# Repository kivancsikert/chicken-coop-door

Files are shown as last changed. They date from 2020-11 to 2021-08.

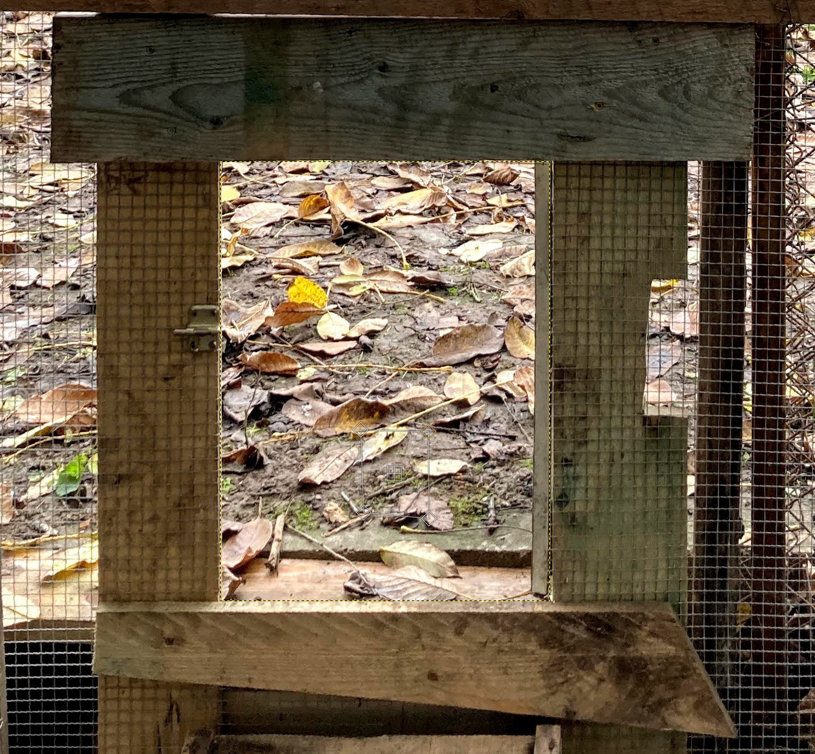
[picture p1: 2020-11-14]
frame.jpg

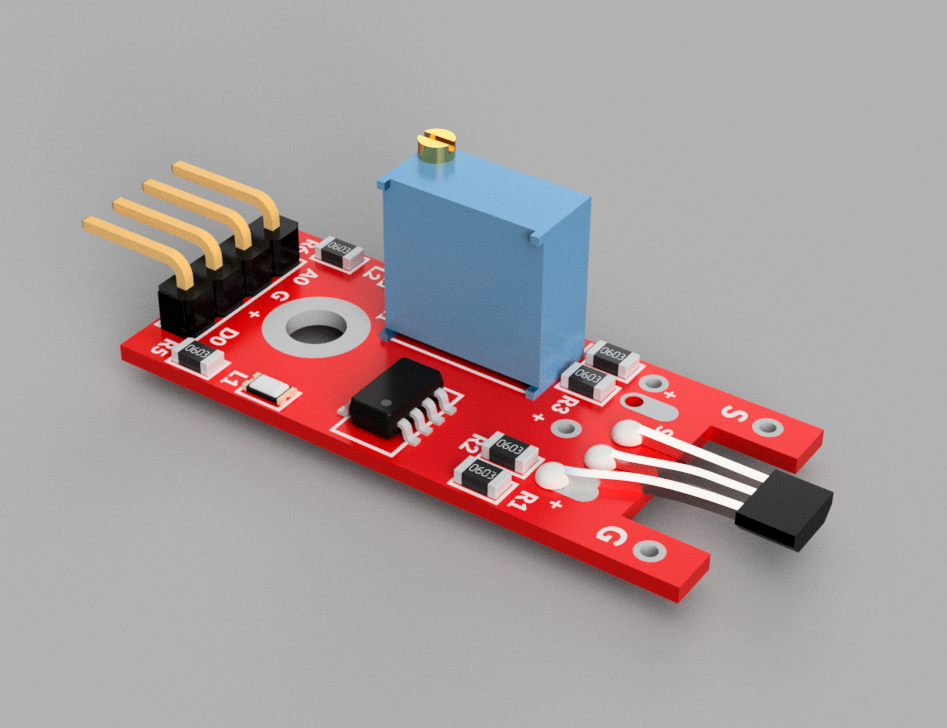
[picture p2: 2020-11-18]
models/ky-024-linear-magnetic-hall-effect-switches-1.snapshot.8/KY-024 Linear Magnetic Hall Effect Switches.png

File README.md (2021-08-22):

# Chicken Coop Door



## Building

-   Place `data/mqtt-config.json` with the following contents used to access the MQTT server:

    ```jsonc
    {
        "host": "broker",                 // MQTT broker host name
        "port": 1883,                     // MQTT broker port
        "clientId": "chicken-door",       // MQTT client ID
        "prefix": "devices/chicken-door"  // MQTT prefix
    }
    ```

-   Deploy file system image.

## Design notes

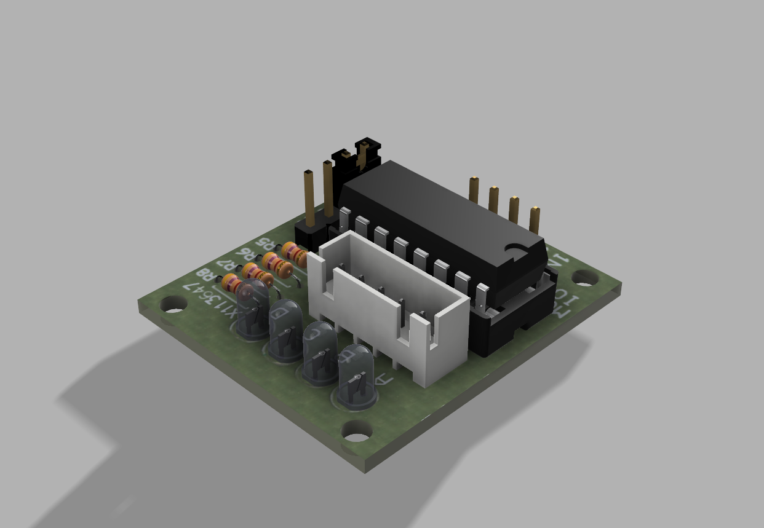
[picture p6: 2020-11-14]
models/uln2003-unipolar-stepper-driver-board-1.snapshot.3/ULN2003 Stepper Driver v18.png

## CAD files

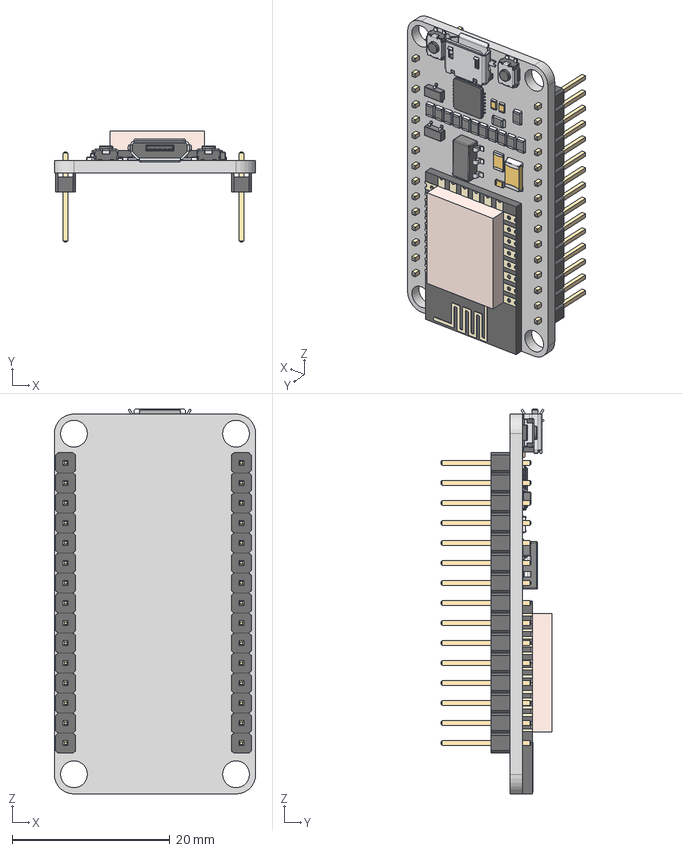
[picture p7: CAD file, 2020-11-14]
models/nodemcu-lua-wifi-esp8266-1.snapshot.4/ESP8266 v7.stp
25.6 x 14.1 x 48.8 mm
micro usb shell
micro usb internal
micro usb contact x 5
switch v1
switch v1 (1)
spacer x 15
pin x 15
spacer (1) (1) x 15
pin (1) (1) x 15
TSOP-5 v4 v1
TSOP-5 v4 v1 (1)
TSOP-5 v4 v1 (1) (1)
R0805-NO v1 x 13
R0805-NO v1 (1) x 2
R0805-NO v1 (1) (1)
R0805-NO v1 (1) (2)
R0805-NO v1 (1) (3)
Cuerpo Microprocesador v1

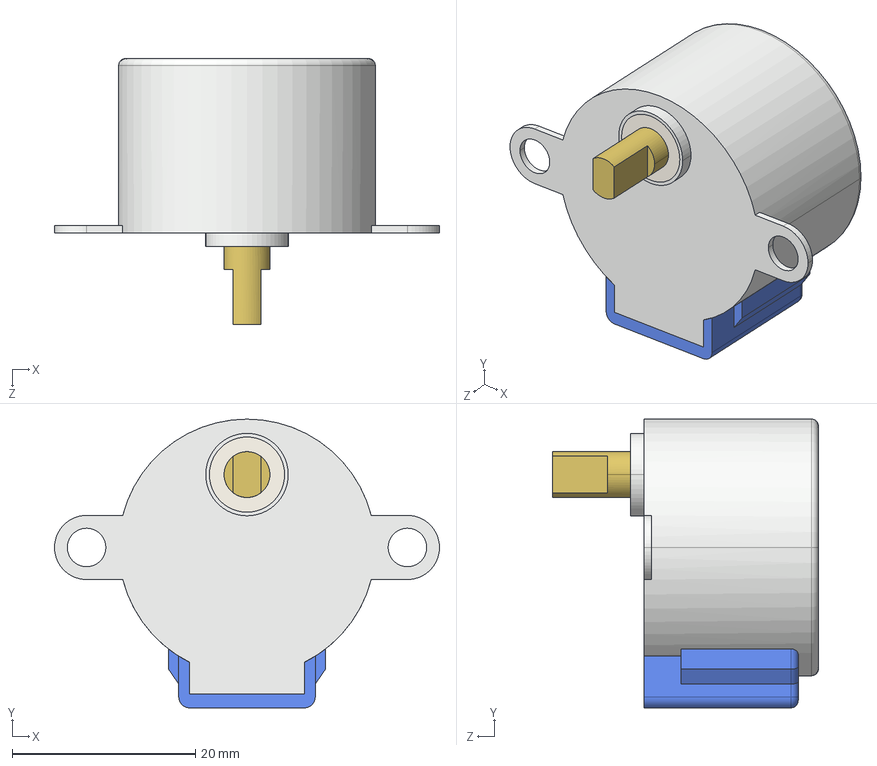
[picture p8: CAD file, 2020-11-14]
models/sm-28byj-48/SM-28BYJ-48_EN_10035505.step
42.0 x 31.5 x 29.0 mm

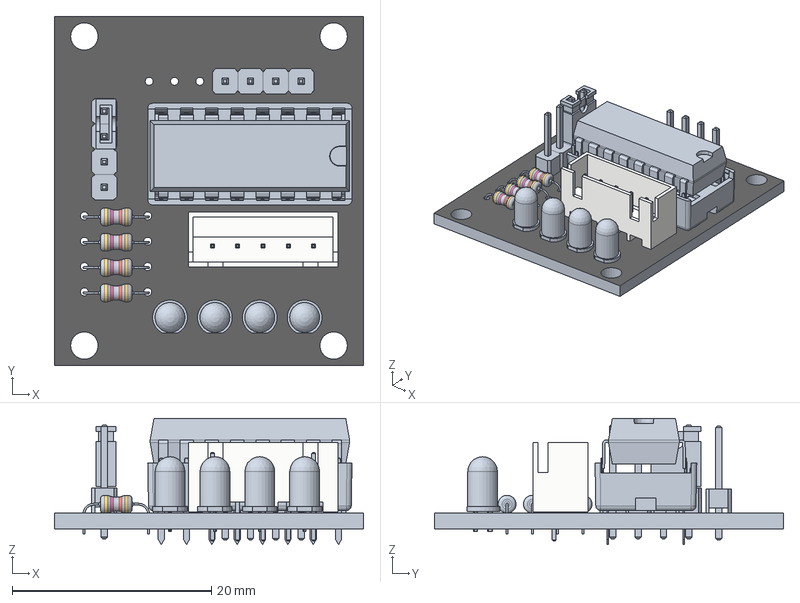
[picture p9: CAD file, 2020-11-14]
models/uln2003-unipolar-stepper-driver-board-1.snapshot.3/ULN2003 Stepper Driver.stp
31.0 x 35.0 x 12.7 mm
pcb
jumper_connector
r205 x 4
conn_lead x 5
spacer x 4
pin x 4
spacer (1) x 4
pin (1) x 4
LED 3mm x 4
package
lead
housing
pins

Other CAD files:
models/nodemcu-lua-wifi-esp8266-1.snapshot.4/ESP8266 v7.f3d
models/nodemcu-lua-wifi-esp8266-1.snapshot.4/Led RGB v4.f3d
models/uln2003-unipolar-stepper-driver-board-1.snapshot.3/ULN2003 Stepper Driver v18.f3d
models/uln2003-unipolar-stepper-driver-board-1.snapshot.3/ULN2003 Stepper Driver.skp
models/uln2003-unipolar-stepper-driver-board-1.snapshot.3/ULN2003 Stepper Driver.stl

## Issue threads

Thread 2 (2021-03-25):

Secure spindle

lptr, 2021-03-25:
The spindle is loose right now. Need to find M3 worm screws (or order new ones) to secure it to the motor shaft.

lptr, 2021-03-28:
New screws ordered.

lptr, 2021-03-30:
Screws arrived, spindle is now secure.

Closed 2021-03-30.

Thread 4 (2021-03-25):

Introduce latency in reacting to light changes

lptr, 2021-03-25:
Currently as soon as we read light levels outside the expected level for the current state, we switch states. This can be problematic, as the door might open if for example a passing car casts some light on the light sensor. Or the door might close if a chicken blocks the sensor for a short time.

lptr, 2021-03-29:
Kálmán filter might be a good solution. Or a moving average. https://en.wikipedia.org/wiki/Kalman_filter

Closed 2021-03-31.

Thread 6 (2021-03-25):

Water-proof housing for light sensor

lptr, 2021-03-25:
It's bare bones right now. It could also use a bent connector, so that it can be mounted flat under the box.

lptr, 2021-04-16:
We now have a water-proof pouch made of a vacuum packing sack. It's good enough to start outside testing I think, but it's not a final solution. I'd rather have something using a pill bottle or something, though I haven't found a suitable device yet.

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

lptr, 2021-05-11:
Light sensor now hides behind controller box in water-proof housing (more or less).

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

Closed 2021-05-11.

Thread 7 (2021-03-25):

Reset button

lptr, 2021-03-25:
Need a button to reset everything to some sort of intial state:

- no wifi configured, wait for SmartConfig
- close at light = 0, open at light = maxint, light reaction latency = 5 sec
- state = open (unknown?)

Closed 2021-03-31.

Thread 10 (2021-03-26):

Report status

lptr, 2021-03-26:
We want data to be available about operations in the field without having to go to the farm all the time.

The brains of the chicken-door is now equipped with GPRS capabilities. Make use of them to send a regular update to some server.

### What frequency should we send data?

Once a minute sounds like frequent enough.

Would be nice to get as much data as we can while still fitting in to the 1 GB limit of the SIM card we have currently per month. That's a quota of roughly 30 MB a day, or 1 MB per hour or 17 kB / minute. For reporting status data that's likely more than enough.

We should use some sort of compression. Protocol buffers might come in handy, but for the first version even raw JSON should do nicely.

If nothing changed since the last report, sending something like "same" should be fine.

### What should we include

We could send different types of data at different times.

#### Per-minute update

- uptime
- light sensor reading
- motor position
- gate state (open, closing etc.)

#### Per-hour update

Send one right after startup, then once every hour with the current configuration.

- open and close light levels, light latency
- motor position extents

(All this data should also be preserved in the flash memory, and reloaded upon reset.)

### Protocol

Some things to clarify:

- Is it best to open a new GPRS connection every time we want to transmit, or to keep one open (and reopen if none is available)?
- What is a good protocol to send the data?
  - JSON over raw HTTP sounds simple, but it isn't secure and it probably wastes a lot of bandwidth (might not be an issue initially)
  - A websocket continuously open over an authenticated HTTPS channel sounds better, though it's unclear how such a client would be implemented on such a limited client.

This library looks workable: https://www.arduino.cc/reference/en/libraries/sim800l-http-connector/

This is another option to implement the GPRS connection, specifically for the LilyGo board: https://randomnerdtutorials.com/esp32-sim800l-publish-data-to-cloud/

### Server implementation

The server could be running on the NAS at home for now, though that would mean opening up the home network, which is probably not a good idea.

lptr, 2021-03-26:
MQTT resources: https://awesomeopensource.com/project/hobbyquaker/awesome-mqtt

lptr, 2021-03-26:
Another description of sending data to Google Cloud IoT Core via Pub/Sub: https://ludovic-emo.medium.com/how-to-send-esp32-telemetry-to-google-cloud-iot-core-caf1a952020d

lptr, 2021-03-28:
Sensor data collection and analytics with IoT Core: https://cloud.google.com/community/tutorials/cloud-iot-enviro-board-workshop

lptr, 2021-03-29:
Data is now in BigQuery and primitive dashboard is shown in Data Studio. We can work on this later to move the data publishing to Google Sheets perhaps.

lptr, 2021-03-30:
Publishing directly via the TTGO GSM module to Google's IoT proved too complicated. Let's move to using an external 3G -> WIFI router and stick with WIFI in the code.

Closed 2021-03-30.

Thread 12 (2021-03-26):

Transmit power to the door

lptr, 2021-03-26:
We need to get 12V power to the door from the chicken house. We could extend the existing 12V charger. Or we can add a water-proof extension coord.

lptr, 2021-05-13:
This is now done using a 4m cable form the chicken coop itself. We've switched to 5V/2A for now as it seems to be enough for everything on board.

Closed 2021-05-13.

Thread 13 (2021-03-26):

Final door design

lptr, 2021-03-26:
The current design is based on drawer rails that are not weather-proof and aree quite tight.

lptr, 2021-04-20:
Opted for 20x20 Bosch-compatible aluminium profiles. It's not cheap, but for prototyping it's perfect as everything has a place on it.

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

lptr, 2021-04-25:
We have the reed relay holders. The only thing missing now are a holder for the light sensor and one for the magnet (although we chould probably reuse the one from the previous design). Oh, yes, and the door itself.

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

lptr, 2021-05-11:
Final door design is done:

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

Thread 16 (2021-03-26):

Calibrate light sensor

lptr, 2021-03-26:
We should put the device in its final place without the door in place just so that we can collect data about light sensor's measurements. We can use these to set the correct open and close light levels.

lptr, 2021-05-13:
Shoving the light sensor in its housing behind between the wall and the enclosure seemed like a good way to protect it from the elements, but it seems that it gets way too little light this way, and the measured light level goes down to 0 already mid-dusk on a cloudy day. Should move it to somewhere where we can still get some protection, but also more light.

lptr, 2021-06-04:
The light sensor works reasonably well now with a close limit of 1 lumen, which today (on close to the longes days) has been reached shortly before 9pm. This is good enough for now.

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

Closed 2021-06-04.

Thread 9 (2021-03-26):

Configure motor position limits

lptr, 2021-03-26:
There should be a maximum and minimum number that are never exceeded to avoid breaking the thread or switching thread spooling direction.

lptr, 2021-03-31:
We should also have some timeouts for how long the motor is allowed to run vs rest to avoid overheating if something goes wrong.

Closed 2021-04-01.

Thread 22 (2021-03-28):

Retry WIFI connection if it does not want to connect

lptr, 2021-03-28:
For some reason sometimes WIFI does not want to connect at bootup time. After a reset it works. Weird. We should try connecting again in such a case after a few seconds.

Closed 2021-03-31.

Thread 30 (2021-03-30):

Try new 3G modem

lptr, 2021-03-30:
Since direct GPRS connections using the TTGO board failed (see #26), we should use WIFI and employ a 3G modem instead.

lptr, 2021-03-30:
I've ordered [M1 Portable 3G WiFi Hotspot IEEE802.11b/g/n 150Mbps RJ45 USB Router](https://www.banggood.com/M1-Portable-3G-WiFi-Hotspot-IEEE802_11b-or-g-or-n-150Mbps-RJ45-USB-Router-p-944487.html), let's see if it can do the trick.

If it works, we can connect it to the TPLink AP, though it doesn't do Power-over-Ethernet, so we still need a separate power cable.

Initially it should be okay to work on its own, though.

lptr, 2021-04-16:
The M1 didn't work out (it's just a WIFI router with a USB port for a 3G stick, and I had to buy a separate stick, which then turned out not to be compatible). However, we now have a TP-LINK M7200.

It even has a 2000 mAh battery for when we have problems with electricity. (One of the things we could monitor actually.)

Without az UTP port we can't directly connect it to the AP, but I think it's going to be fine to get us started, and later we can invest in better equipment.

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

Closed 2021-04-16.

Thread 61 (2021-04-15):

Close light limit not observed

lptr, 2021-04-15:
These are the current settings:

```json
{
    "openLightLimit": 60,
    "closeLightLimit": 5,
    "lightUpdateInterval": 750,
    "lightLatencyInterval": 10000,
    "motorEnabled": true,
    "movementTimeout": 60000,
    "invertOpenSwitch": true,
    "invertCloseSwitch": true,
    "wifiSsid": "Baszanyek 2.4",
    "wifiPassword": "bOR0f2Lv6nujW2Co",
    "statePublishingInterval": 5000
}
```

Yet we seem to be both opening (correct) and closing (incorrect) at `light == 60`. Why aren't we observing the close limit?

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

lptr, 2021-04-15:
Fixed by d02135c37a19bd0c8092f6c9fcf6f8714d7d2571.

Closed 2021-04-15.

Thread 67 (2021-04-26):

Set up MQTT bridge to allow non-secure clients

lptr, 2021-04-26:
Currently each device needs to do TLS 1.2 to talk to Google IoT cloud directly. This is a lot to ask from an ESP8266 I think. It would be better if we could install a Raspberry Pi as a broker/bridge/gateway that would do the TLS 1.2 connection to Google IoT, and each device with its own ESP8266 or ESP32 could use an unsecure connection over the local WIFI to this gateway, but still use MQTT.

lptr, 2021-04-26:
This SO topic states that Google does not support sub-brokers as of now:

https://stackoverflow.com/questions/53372656/connect-local-mosquitto-mqtt-broker-to-google-cloud-iot

That is quite sad. We should investigate further.

lptr, 2021-04-26:
This is a description about a _gateway,_ but it is unclear if the devices can use MQTT themselves: https://cloud.google.com/community/tutorials/cloud-iot-gateways-rpi

lptr, 2021-04-26:
This is what we need:

http://www.steves-internet-guide.com/mosquitto-bridge-configuration/

lptr, 2021-04-26:
There is a thing called a "gateway" in Google IoT, too:

- https://cloud.google.com/iot/docs/how-tos/gateways
- https://cloud.google.com/iot/docs/how-tos/gateways/mqtt-bridge

lptr, 2021-08-14:
We now have a setup where an RPi 4B (`barn.local`) relays MQTT to `motherhen.kertkaland.com`. \o/

Closed 2021-08-14.

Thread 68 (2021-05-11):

Re-crimp JST connectors

lptr, 2021-05-11:
They are sometimes malfunctioning, especially the one on the motor driver side.

lptr, 2021-05-13:
This don't seem to be necessary. The motor driver was malfunctioning because it has non-JST connectors, and the purple one has partially disconnected.

The current setup should be good for the time being. We should re-consider how the connectors work once we mvoe to a DC motor (#51) or to DRV8825 (#50).

Closed 2021-05-13.

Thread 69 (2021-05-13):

Messages don't arrive in Slack

lptr, 2021-05-13:
Sometimes only the "closing" / "opening" message arrives, but not the "clsoed" / "open" message. Rigth now the "initialized" message arrived after a remote reset, but nothing about the door moving, yet in reality it opened properly.

lptr, 2021-05-13:
OK, so the messages are triggered by _state_ updates. Those are throttled to 1/sec, which explains why "initialized" arrived but not "opening" (as it must have followed very quickly). However, it doesn't really explain why "open" did not arrive some 40-50 seconds later. Could it be that Google IoT penalizes frequent state updates with not delivering them for some time?

lptr, 2021-05-13:
In any case, we should stop using state, and only publish stuff as telemetry, which is not throttled. Maybe use different subtopics for what is currently state and telemetry.

Closed 2021-05-16.

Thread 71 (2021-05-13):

Update firmware remotely

lptr, 2021-05-13:
It would be nice to be able to push new versions of the code to the remote machine without having to actually walk up to it. OTA helps with not needing a USB cable, but it still requires direct connection to the WIFI, so have to travel to the garden.

We have some options to make this work from afar:

* There is https://github.com/esmil/arduino-netboot that can check an (ethernet) network for an updated firmware.
* This article discusses using TFTP to upload a new firmware image to the device, and use that during the next boot: https://www.freetronics.com.au/pages/how-to-upload-a-sketch-to-your-arduino-via-a-network

The latter approach seems like the more interesting for now at least.

The "Frankenstein" firmware has built-in support for TFTP-based firmware update for ESP8266: https://github.com/nekromant/esp8266-frankenstein

lptr, 2021-05-16:
This might be another approach, publishing the firmware to HTTP: https://www.instructables.com/Set-Up-an-ESP8266-Automatic-Update-Server/

lptr, 2021-05-16:
OK, so Arduino already includes `HTTPUpdate.h` that does the above!

lptr, 2021-05-16:
This is the request the server gets:

```text
ERROR:root:Host: 10.180.1.216:4443
User-Agent: ESP32-http-Update
Connection: close
Cache-Control: no-cache
x-ESP32-STA-MAC: C4:4F:33:56:F8:D5
x-ESP32-AP-MAC: C4:4F:33:56:F8:D6
x-ESP32-free-space: 1310720
x-ESP32-sketch-size: 1070160
x-ESP32-sketch-md5: 849648aac453f6b62ca0b5a5ba2912ce
x-ESP32-sketch-sha256: CFB7A42FCD60BCCD3FF000ED59A030B6F01A14CD3FF43C9C0A205D96D8B77663
x-ESP32-chip-size: 4194304
x-ESP32-sdk-version: v3.3.5-1-g85c43024c
x-ESP32-mode: sketch
x-ESP32-version: 0.1-107-gaa4c396-dirty
```

lptr, 2021-05-16:
These are the headers we get:

```text
ERROR:root:Host: 10.180.1.216:4443
User-Agent: ESP32-http-Update
Connection: close
Cache-Control: no-cache
x-ESP32-STA-MAC: xx:xx:xx:xx:xx:xx
x-ESP32-AP-MAC: xx:xx:xx:xx:xx:xy
x-ESP32-free-space: 1310720
x-ESP32-sketch-size: 1070160
x-ESP32-sketch-md5: 849648aac453f6b62ca0b5a5ba2912ce
x-ESP32-sketch-sha256: CFB7A42FCD60BCCD3FF000ED59A030B6F01A14CD3FF43C9C0A205D96D8B77663
x-ESP32-chip-size: 4194304
x-ESP32-sdk-version: v3.3.5-1-g85c43024c
x-ESP32-mode: sketch
x-ESP32-version: 0.1-107-gaa4c396-dirty
```

lptr, 2021-05-16:
We probably should publish to GitHub pages, though the feature is currently down, so we can't test it.

lptr, 2021-05-16:
Let's test this with the firmware published to GitHub pages.

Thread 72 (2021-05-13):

Need a way to override state

lptr, 2021-05-13:
If the light detection malfunctions, we need a way to manually force it open or closed from afar. In the past using `{ setState: 2}` (i.e. `OPENING`) worked, but it doesn't anymore.

Another approach is to set the open/close light threshold to something extreme, like `-1` or `999999`, but it's inconvenient to revert later on.

It would also be nice to have a nicer API to trigger the change. It would be nice not to have to remember numbers, but typing quotes on a phone is not easy either, as they get converted to typographic quotes, so maybe numbers are the best option.

There are a couple things we could do here wrt making  the command nicer:

* replace `setState` with `state`
* redefine the gate state constants to be more meaningful:
  * `-2` to mean closed
  * `-1` to mean closing
  * `1` to mean opening
  * `2` meaning open

This way `0` could mean "just initialized" / "unknown" if we need that. It could also mean "emergency stop".

We should probably update the state of the door based on the state of the switches, too. In any case we should respond to the situation when the motor is overwhelmed and lets the door fall back from an open position. In such a case we should probably trigger emergency stop, too.

lptr, 2021-05-14:
It would be good to override with a timeout, say, "keep open for two hours, then return to the normal program."

Closed 2021-05-16.

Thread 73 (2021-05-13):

Web app to control the door

lptr, 2021-05-13:
Add a web app that shows most recent data, and allows certain commands to be sent to the device.

Operations to be made available:

- open the door
- close the door
- enable emergency stop
- restart the door

The web app should show the following information for the past 24 hours:

- door position
- light values
- open and close switch states
- door state

It should also display the firmware version running on the device.

lptr, 2021-09-07:
We now have a NodeRED UI dashboard to control the door.

Closed 2021-09-07.

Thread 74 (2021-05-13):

Automated testing

lptr, 2021-05-13:
Especially now that the hardware is on site, we need a way to run automated tests using the code only.

lptr, 2021-08-08:
https://github.com/mum4k/arduino_abstractions/ uses Google Test

It can also be built with Bazel, and there appear to be PlatformIO rules for Bazel, too: https://github.com/mum4k/platformio_rules (should use 0.0.9 instead of 0.0.5, but it seems to work).

lptr, 2021-08-08:
In any case, using Google Test sounds like the way to go.

lptr, 2021-09-01:
This looks interesting: https://piolabs.com/blog/insights/unit-testing-part-1.html

lptr, 2021-09-07:
OK, with #135 we now have automated testing in place using GoogleTest.

Closed 2021-09-07.

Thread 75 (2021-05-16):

Support multiple WIFI configurations

lptr, 2021-05-16:
Would be nice if we didn't have to switch between them when moving the device between locations, but it could remember a couple different configurations.

lptr, 2021-06-04:
Let's use the same WIFI config in both locations for now instead.

Closed 2021-06-04.

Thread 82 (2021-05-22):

Better light sensor

lptr, 2021-05-22:
The current light sensor hits its sensitivity limit at dusk, even when packaged into a clear glass case. We need something more sensitive.

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

lptr, 2021-06-04:
The current light sensor hits 0 lumens around 9pm on the longest days, which should be good enough.

Closed 2021-06-04.

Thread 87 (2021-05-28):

Solar power

lptr, 2021-05-28:
It should be possible to run the whole shebang from solar power. We would probably need to switch to ESP8266 (see #53), and use a 3.3V DC motor to make sure the ~4V coming off a simple solar panel is enough for everything.

lptr, 2021-05-28:
Here's a project using a cheap TP 4056 charging board to charge a small battery for weather station: https://www.instructables.com/Solar-Powered-WiFi-Weather-Station/

lptr, 2021-05-28:
https://www.aliexpress.com/item/4000354927382.html

CN3065 might be another cheap alternative charger.

lptr, 2021-05-28:
This one explains what a solar charger needs to do: https://www.youtube.com/watch?v=0sfjsHjS62g

I guess MPPT is important to maximize charging, but it's not really that important for us as long as there is enough power to keep the battery charged. Fast charging is not a priority.

lptr, 2021-05-28:
This says that you can power even an ESP32 via its 3.3V input using a TP 4056: https://randomnerdtutorials.com/power-esp32-esp8266-solar-panels-battery-level-monitoring/

lptr, 2021-06-06:
Some ideas on reducing power consumption:

* ESP32: https://lastminuteengineers.com/esp32-sleep-modes-power-consumption/
* ESP8266: https://www.instructables.com/ESP8266-Pro-Tips/

*Modem sleep* sounds like a good, simple approach to reduce the consumption enough so that the device can work even on a 2200mAh battery. It is available on both the ESP32 and the ESP8266.

> In Modem-sleep mode, ESP8266 will close the Wi-Fi module circuit between the two DTIM
Beacon intervals in order to save power. ESP8266 will be automatically woken up before
the next Beacon arrival. The sleep time is decided by the DTIM Beacon interval time of the
router. During sleep, ESP8266 can stay connected to the Wi-Fi and receive the interactive
information from a mobile phone or server.

https://www.espressif.com/sites/default/files/9b-esp8266-low_power_solutions_en_0.pdf

ESP8266 sleep mode power consumption:

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

From: https://bbs.espressif.com/viewtopic.php?t=133

With deep sleep it seems that we can practically schedule a reboot at a later time, and consume very little power until than while being for all practical purposes dead.

Light sleep is a bit unclear, how waking up happens there. IIUC, it wakes up when receiving WIFI messages:

> Light-sleep mode can be used in the scenarios where the applications need to stay
connected to the router and can respond to the sending data from the router in real time.
The CPU can be idle before receiving commands. An example is the Wi-Fi switch whose
CPU is idle for most of the time and only performs GPIO operations until receiving the
control commands.

This might not be useful for us, though.

But even with just modem-sleep (which seems to be enabled by default) and receiving/transmitting for 1 second every minute (assuming we only need to transmit to the local RPi, so it's fast) our power consumption would be something like each minute:

(1 * 150 mA + 59 * 15 mA) / 60 = 17.25 mA

So if there was no motor or sensor to handle, our 2000 mAh battery would last for ~116 hours.

An ESP8266 would take 414 mAh a day, while an ESP32 would take a bit more, say 600 mAh.

The BH1750 light sensor consumption is around 0.12mA, which comes in at 2.88 mAh per day:

> It operates on voltage range of 2.4V-3.6V and consumes really small current of 0.12mA.

https://components101.com/sensors/bh1750-ambient-light-sensor

The reed relays shouldn't use much electricity themselves.

So that leaves around 1400 mAh for the motor itself, assuming the solar panel can fully recharge the battery through the day.

lptr, 2021-06-06:
This says the 28BYJ-48 takes 240 mA when running (we have it disabled when not), so the remaining 1400 mAh should be enough to run the motor for 5.8 hours a day. We only need it for about a minute or two twice a day (240 mA * 4 / 60 = 16 mAh per day), so unless it (or the driver board) consumes a significant amount of power even when idle, we should be good.

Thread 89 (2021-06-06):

Let door open and close even when network connection is problematic

lptr, 2021-06-06:
Currently, when the MQTT server in the cloud cannot be reached (because the 3G network is unavailable) everything stops, and the door does not move up or down until the network connection is restored.

It's not completely clear why this happens, but the door should function even if the remote server is not available.

In a future version we'll have a local Raspberry Pi act as MQTT server, so the need to handle 3G problems will go away. But some more resiliency against network issues will still be welcome even then.

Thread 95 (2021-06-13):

Check if real time clock can be persistent

lptr, 2021-06-13:
Do we need to connect NTP every time the ESP boots, or can the time survive between reboots (maybe as long as there's constant power)?

lptr, 2021-08-14:
ESPs don't seem to have a persistent RTC.

Closed 2021-08-14.

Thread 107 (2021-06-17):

Use interrputs to detect open/close state

lptr, 2021-06-17:
This way we can do network on the main thread without having to worry about missing the signal, even with a DC motor.

lptr, 2021-08-08:
This is now closed via #119.

Closed 2021-08-08.

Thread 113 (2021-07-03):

Upgrade to 12V stepper motor

lptr, 2021-07-03:
Use the stronger, 12V variant of 28BYJ-48 with 12V input power. Install the whole thing on a prototype board.

- [x] code update (see #114)
- [x] light sensor cable (4 pin -> 5 pin)
- [x] light sensor holder
- [x] power cable (3.5 mm jack extender, 4m+)
- [x] holder for prototype board inside enclosure

Schematic:

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

lptr, 2021-07-03:
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

lptr, 2021-07-03:
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

lptr, 2021-08-14:
This is now installed.

Closed 2021-08-14.

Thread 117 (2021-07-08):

Send MQTT event before updating firmware

lptr, 2021-07-08:
So we know what we are updating to, and if the update started at all.

We might as well add a command to force a status message, too, to check afterwards. At least until #94 is fixed.

lptr, 2021-09-07:
Since #130 the lost init message is not a problem anymore. We should still send an event before the update begins.

lptr, 2021-09-08:
This just doesn't seem to work. I've added a ping command (see #149). This can be used to check if the device is up and running before sending the update command.

Closed 2021-09-08.

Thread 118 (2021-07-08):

NTP takes a long time to reconnect to

lptr, 2021-07-08:
It seems that we have regular outages between 5-6 PM every day, roughly at the same time. It coincides with the time the device was last initialized, so it seems that it's related to the 24 hour NTP refresh period, maybe. The outages seem to be growing longer every day, but that might be just false perception.

lptr, 2021-07-08:
I've bumped the NTP refresh time to 7 days in #115. It will clarify if the outages are related to the NTP refresh or not.

lptr, 2021-07-26:
It has stopped completely now:

```text
Chicken DoorAPP  11:55 AM
No heartbeat for test-device for 711.576 seconds since Sat Jul 24 2021 09:43:12 GMT+0000 (Coordinated Universal Time) (timeout is 300 seconds).
white_check_mark
eyes
raised_hands

12:00
No heartbeat for test-device for 1009.933 seconds since Sat Jul 24 2021 09:43:12 GMT+0000 (Coordinated Universal Time) (timeout is 300 seconds).

Chicken DoorAPP  12:05 PM
Received fresh heartbeat for test-device at Sat Jul 24 2021 10:04:55 GMT+0000 (Coordinated Universal Time).

Chicken DoorAPP  8:44 PM
The door is now closing on test-device.
{"version":"0.1-183-ga7fcbce-dirty","event":{"state":-1},"telemetry":{"uptime":1383366987,"light":0,"openSwitch":true,"closedSwitch":false,"manualOverride":false,"emergencyStop":false,"gate":-1,"motorPosition":23}}
white_check_mark
eyes
raised_hands

8:46
The door is now closed on test-device.
{"version":"0.1-183-ga7fcbce-dirty","event":{"state":-2},"telemetry":{"uptime":1383443164,"light":0,"openSwitch":false,"closedSwitch":true,"manualOverride":false,"emergencyStop":false,"gate":-2,"motorPosition":-23615}}

Chicken DoorAPP  6:05 AM
No heartbeat for test-device for 552.588 seconds since Sun Jul 25 2021 03:55:49 GMT+0000 (Coordinated Universal Time) (timeout is 300 seconds).
6:10
No heartbeat for test-device for 852.578 seconds since Sun Jul 25 2021 03:55:49 GMT+0000 (Coordinated Universal Time) (timeout is 300 seconds).

Chicken DoorAPP  6:15 AM
No heartbeat for test-device for 1154.04 seconds since Sun Jul 25 2021 03:55:49 GMT+0000 (Coordinated Universal Time) (timeout is 300 seconds).
6:20
No heartbeat for test-device for 1453.278 seconds since Sun Jul 25 2021 03:55:49 GMT+0000 (Coordinated Universal Time) (timeout is 300 seconds).
```

lptr, 2021-09-07:
This is not an issue anymore, probably since #115.

Closed 2021-09-07.

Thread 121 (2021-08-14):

Switch to `barn.local` as MQTT target

lptr, 2021-08-14:
We need to switch to using the local MQTT server. In the development environment this will be the one running on the NAS, for the farm environment it will be `barn.local` (see #120).

Depends on #120.

Requires a few things:

### In source code

- [x] drop Google as MQTT backend and switch to regular MQTT instead
- [x] add configuration for MQTT host (should be `nasi.local` at home and `barn.local` at farm)

### On cloud server

- set up MQTT relay and Grafana views – kivancsikert/motherhen-docker#1
- set up Slack notifications in NodeRED - https://github.com/kivancsikert/motherhen-docker/issues/8

### On `barn.local`

- install `barn.local` at farm - https://github.com/kivancsikert/barn-docker/issues/1
- set up Slack notifications about unavaliable cloud server on `barn.local`

Closed 2021-08-20.

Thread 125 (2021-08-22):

Allow door to work without MQTT connection

lptr, 2021-08-22:
Since switching back to a local MQTT, a faulty MQTT connection prevents the motor from running.

Closed 2021-08-22.

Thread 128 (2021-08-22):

Fix MDNS lookup of the MQTT server

lptr, 2021-08-22:
It looks like we can't resolve host names via MDNS.

Tried these:

- `barn` works
- `barn.local` does not work
- `nasi` and `nasi.local` both don't work

It _seems_ like regular hostname lookups should do MDNS queries already, but there is a problem where `.local` is automatically appended (see https://github.com/espressif/esp-idf/issues/6590). This is what seems to be happening in the case of `barn.local`, maybe. It is not what's happening in the case of `nasi.local`, though.

lptr, 2021-08-22:
We could try to explicitly look up the MDNS name. Maybe that would help.

There is also a `LWIP_DNS_SUPPORT_MDNS_QUERIES` macro that is set to `0` by default, and can be set to `1` to enable MDNS lookups for regular queries:

> if you want general dns lookup to support mdns then lwip has to be compiled with LWIP_DNS_SUPPORT_MDNS_QUERIES

https://github.com/espressif/esp-idf/issues/2507#issuecomment-782928116

I've tried setting that via `platformio.ini`, but it doesn't seem to change anything.

lptr, 2021-08-22:
The ESP32 lwIP stack has this to say:

> mDNS uses a different implementation to the lwIP default mDNS (see mDNS Service), but lwIP can look up mDNS hosts using standard APIs such as gethostbyname() and the convention hostname.local, provided the CONFIG_LWIP_DNS_SUPPORT_MDNS_QUERIES setting is enabled.

https://docs.espressif.com/projects/esp-idf/en/latest/esp32/api-guides/lwip.html

lptr, 2021-08-22:
That option looks like it's enabled by default in ESP-IDF `master`, though 4.3 doesn't say anything about the default value. And we are currently compiling against ESP-IDF 4.3: https://github.com/platformio/platform-espressif32/releases/tag/v3.3.0

lptr, 2021-08-22:
...that said, this is the code in  `lwip/opt.h` that is very much compiled as part of the code:

```c++
/** Set this to 1 to enable querying ".local" names via mDNS
 *  using a One-Shot Multicast DNS Query */
#if !defined LWIP_DNS_SUPPORT_MDNS_QUERIES || defined __DOXYGEN__
#define LWIP_DNS_SUPPORT_MDNS_QUERIES  0
#endif
```

So setting this to `1` via the command line seems to make sense, though I see no effect. :/

lptr, 2021-08-22:
That's because `dns.c`, where the macro is used, is not compiled with the application. I guess it comes pre-built as part of the arduino core for ESP32, and we only link against it...

lptr, 2021-08-22:
Let's add an explicit workaround for now.

Closed 2021-08-22.

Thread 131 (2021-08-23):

Try AsyncMqttClient

lptr, 2021-08-23:
Maybe we can connect more smoothly, without interrupting the motor.

lptr, 2021-11-05:
Not now. If it comes up again, let's reevaluate if it's worth it.

Closed 2021-11-05.

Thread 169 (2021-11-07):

Motor weak

lptr, 2021-11-07:
This has started happening in 3.0.9.

lptr, 2021-11-07:
Git bisect says it's in this commit: 905c3befe9b10f56a331e421ae6461bb948e4617

lptr, 2021-11-07:
Indeed, the bug has been introduced here:

https://github.com/kivancsikert/chicken-coop-door/commit/905c3befe9b10f56a331e421ae6461bb948e4617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

Originally, we passed the pins in order 1-3-2-4 to the motor, but after the change we send them 1-2-3-4. 🤦

Closed 2021-11-07.

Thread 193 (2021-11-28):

Move switch settings to device configuration

lptr, 2021-11-28:
The following entries in `config.json` should be in `device-config.json` instead:

```jsonc
        "invertOpenSwitch": true, // Invert open switch
        "invertCloseSwitch": true, // Invert close switch
        "stickySwitches": false // Keep switches engaged after they are hit once
```

As these properties belong to the hardware configuration.

lptr, 2021-11-29:
```diff
diff --git a/README.md b/README.md
index c501cd9..027fca1 100644
--- a/README.md
+++ b/README.md
@@ -51,9 +51,6 @@ It's structure is the following:
         "closeDelay": 1200, // Seconds to delay after close limit is reached before closing
         "motorEnabled": true, // Whether the motor is allowed to move
         "movementTimeout": 120, // Timeout in seconds before emergency stop is engaged
-        "invertOpenSwitch": true, // Invert open switch
-        "invertCloseSwitch": true, // Invert close switch
-        "stickySwitches": false // Keep switches engaged after they are hit once
     },
     "publishingInterval": 5 // Seconds between telemetry reports
 }
diff --git a/src/DeviceConfig.hpp b/src/DeviceConfig.hpp
index c4d5480..3113c66 100644
--- a/src/DeviceConfig.hpp
+++ b/src/DeviceConfig.hpp
@@ -17,7 +17,10 @@ public:
         gpio_num_t lightScl,
         gpio_num_t openSwitch,
         gpio_num_t closeSwitch,
-        gpio_num_t resetButton)
+        gpio_num_t resetButton,
+        bool invertOpenSwitch,
+        bool invertCloseSwitch,
+        bool stickySwitches)
         : motor1(motor1)
         , motor2(motor2)
         , motor3(motor3)
@@ -26,12 +29,19 @@ public:
         , lightScl(lightScl)
         , openSwitch(openSwitch)
         , closeSwitch(closeSwitch)
-        , resetButton(resetButton) {
+        , resetButton(resetButton)
+        , invertOpenSwitch(invertOpenSwitch)
+        , invertCloseSwitch(invertCloseSwitch)
+        , stickySwitches(stickySwitches) {
     }

-    void print() {
+    void print() const {
         Serial.printf("PinLayout: motor: [%d, %d, %d, %d], light SDA: %d, light SCL: %d, open: %d, close: %d, reset: %d\n",
             motor1, motor2, motor3, motor4, lightSda, lightScl, openSwitch, closeSwitch, resetButton);
+        Serial.printf("Switches: invert open: %s, invert close: %s, sticky: %s\n",
+            invertOpenSwitch ? "true" : "false",
+            invertCloseSwitch ? "true" : "false",
+            stickySwitches ? "true" : "false");
     }

     const gpio_num_t motor1;
@@ -43,6 +53,9 @@ public:
     const gpio_num_t openSwitch;
     const gpio_num_t closeSwitch;
     const gpio_num_t resetButton;
+    const bool invertOpenSwitch;
+    const bool invertCloseSwitch;
+    const bool stickySwitches;
 };

 class DeviceConfig
@@ -63,14 +76,18 @@ protected:
                 GPIO_NUM_23, GPIO_NUM_19, GPIO_NUM_18, GPIO_NUM_5,    // Motor 1, 2, 3, 4
                 GPIO_NUM_15, GPIO_NUM_13,                             // Light SDA, SCL
                 GPIO_NUM_14, GPIO_NUM_12,                             // Open switch, close switch
-                GPIO_NUM_2                                            // Reset button
+                GPIO_NUM_2,                                           // Reset button
+                true, true,                                           // Invert switches
+                true                                                  // Sticky switches
             );
         } else if (model.get() == "mk3") {
             pinLayout = new PinLayout(
                 GPIO_NUM_23, GPIO_NUM_19, GPIO_NUM_18, GPIO_NUM_5,    // Motor 1, 2, 3, 4
                 GPIO_NUM_21, GPIO_NUM_22,                             // Light SDA, SCL
                 GPIO_NUM_14, GPIO_NUM_12,                             // Open switch, close switch
-                GPIO_NUM_2                                            // Reset button
+                GPIO_NUM_2,                                           // Reset button
+                true, true,                                           // Invert switches
+                false                                                 // Sticky switches
             );
         } else {
             fatalError("Unknown device model: " + model.get());
diff --git a/src/DoorHandler.hpp b/src/DoorHandler.hpp
index 75fdea7..c1799fe 100644
--- a/src/DoorHandler.hpp
+++ b/src/DoorHandler.hpp
@@ -59,23 +59,6 @@ public:
          * After that time the motor will stop and the door will be disabled.
          */
         Property<seconds> movementTimeout { this, "movementTimeout", minutes { 1 } };
-
-        /**
-         * Whether to invert the "gate open" switch or not.
-         */
-        Property<bool> invertOpenSwitch { this, "invertOpenSwitch", true };
-
-        /**
-         * Whether to invert the "gate close" switch or not.
-         */
-        Property<bool> invertCloseSwitch { this, "invertCloseSwitch", true };
-
-        /**
-         * Whether door should stay open/closed even after switch is released.
-         * This is to help with debugging when the switches are substituted by
-         * a button.
-         */
-        Property<bool> stickySwitches { this, "stickySwitches", false };
     };

     DoorHandler(
@@ -108,7 +91,8 @@ public:
         });
     }

-    void begin(std::function<bool(std::function<void(JsonObject&)>)> onEvent) {
+    void begin(bool stickySwitches, std::function<bool(std::function<void(JsonObject&)>)> onEvent) {
+        this->stickySwitches = stickySwitches;
         this->onEvent = onEvent;

         motor.initialize();
@@ -155,9 +139,9 @@ protected:
         }

         bool openSwitchEngaged = openSwitch.isEngaged()
-            || (config.stickySwitches.get() && state == State::OPEN);
+            || (stickySwitches && state == State::OPEN);
         bool closeSwitchEngaged = closeSwitch.isEngaged()
-            || (config.stickySwitches.get() && state == State::CLOSED);
+            || (stickySwitches && state == State::CLOSED);
         Direction switchState = closeSwitchEngaged
             ? Direction::CLOSE
             : openSwitchEngaged
@@ -259,6 +243,7 @@ private:
     SwitchHandler& openSwitch;
     SwitchHandler& closeSwitch;
     const Config& config;
+    bool stickySwitches;

     std::function<bool(std::function<void(JsonObject&)>)> onEvent;

diff --git a/src/SwitchHandler.hpp b/src/SwitchHandler.hpp
index 4638d1d..b8e9974 100644
--- a/src/SwitchHandler.hpp
+++ b/src/SwitchHandler.hpp
@@ -8,19 +8,19 @@ using namespace farmhub::client;
 class SwitchHandler
     : public TelemetryProvider {
 public:
-    SwitchHandler(const String& name, const Property<bool>& invertSwitch)
-        : name(name)
-        , invertSwitch(invertSwitch) {
+    SwitchHandler(const String& name)
+        : name(name) {
     }

-    void begin(int pin) {
+    void begin(int pin, bool invert) {
         this->pin = pin;
+        this->invert = invert;
         pinMode(pin, INPUT_PULLUP);
     }

     bool isEngaged() {
         int state = digitalRead(pin);
-        return state != invertSwitch.get();
+        return state != invert;
     }

 protected:
@@ -30,6 +30,6 @@ protected:

 private:
     const String name;
-    const Property<bool>& invertSwitch;
     int pin;
+    bool invert;
 };
diff --git a/src/main.cpp b/src/main.cpp
index 77292f9..db6f22d 100644
--- a/src/main.cpp
+++ b/src/main.cpp
@@ -24,8 +24,6 @@ public:
         , telemetryPublisher(tasks(), config.publishingInterval, mqtt())
         , ntp(tasks(), mdns())
         , light(tasks(), config.light)
-        , openSwitch("openSwitch", config.door.invertOpenSwitch)
-        , closeSwitch("closedSwitch", config.door.invertCloseSwitch)
         , door(tasks(), mqtt(), motor, light, openSwitch, closeSwitch, config.door) {
         telemetryPublisher.registerProvider(motor);
         telemetryPublisher.registerProvider(light);
@@ -40,9 +38,9 @@ protected:
         ntp.begin();
         motor.begin(pinLayout.motor1, pinLayout.motor2, pinLayout.motor3, pinLayout.motor4);
         light.begin(pinLayout.lightSda, pinLayout.lightScl);
-        openSwitch.begin(pinLayout.openSwitch);
-        closeSwitch.begin(pinLayout.closeSwitch);
-        door.begin([&](std::function<void(JsonObject&)> populateEvent) {
+        openSwitch.begin(pinLayout.openSwitch, pinLayout.invertOpenSwitch);
+        closeSwitch.begin(pinLayout.closeSwitch, pinLayout.invertCloseSwitch);
+        door.begin(pinLayout.stickySwitches, [&](std::function<void(JsonObject&)> populateEvent) {
             return mqtt().publish("status", [&, populateEvent](JsonObject& root) {
                 root["model"] = deviceConfig.model.get();
                 root["description"] = deviceConfig.description.get();
@@ -79,8 +77,8 @@ private:
     TelemetryPublisher telemetryPublisher;
     NtpHandler ntp;
     LightHandler light;
-    SwitchHandler openSwitch;
-    SwitchHandler closeSwitch;
+    SwitchHandler openSwitch { "open" };
+    SwitchHandler closeSwitch { "closed" };
     AccelMotorHandler motor { tasks() };
     DoorHandler door;
 };
```

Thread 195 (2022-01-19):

WIFI does not reconnect when dropped

lptr, 2022-01-19:
The device lost connection and was printing this on a loop:

```text
Waiting to connect to MQTT until WIFI is available
[E][WiFiUdp.cpp:219] parsePacket(): could not receive data: 5
Waiting to connect to MQTT until WIFI is available
[E][WiFiUdp.cpp:219] parsePacket(): could not receive data: 5
Waiting to connect to MQTT until WIFI is available
[E][WiFiUdp.cpp:219] parsePacket(): could not receive data: 5
Waiting to connect to MQTT until WIFI is available
[E][WiFiUdp.cpp:219] parsePacket(): could not receive data: 5
Waiting to connect to MQTT until WIFI is available
[E][WiFiUdp.cpp:219] parsePacket(): could not receive data: 5
Waiting to connect to MQTT until WIFI is available
[E][WiFiUdp.cpp:219] parsePacket(): could not receive data: 5
Waiting to connect to MQTT until WIFI is available
[E][WiFiUdp.cpp:219] parsePacket(): could not receive data: 5
Overflow in publish queue, dropping message
Not updating NTP because WIFI is not available
Waiting to connect to MQTT until WIFI is available
[E][WiFiUdp.cpp:219] parsePacket(): could not receive data: 5
Waiting to connect to MQTT until WIFI is available
[E][WiFiUdp.cpp:219] parsePacket(): could not receive data: 5
Waiting to connect to MQTT until WIFI is available
[E][WiFiUdp.cpp:219] parsePacket(): could not receive data: 5
Waiting to connect to MQTT until WIFI is available
[E][WiFiUdp.cpp:219] parsePacket(): could not receive data: 5
Waiting to connect to MQTT until WIFI is available
[E][WiFiUdp.cpp:219] parsePacket(): could not receive data: 5
Waiting to connect to MQTT until WIFI is available
[E][WiFiUdp.cpp:219] parsePacket(): could not receive data: 5
Waiting to connect to MQTT until WIFI is available
[E][WiFiUdp.cpp:219] parsePacket(): could not receive data: 5
Waiting to connect to MQTT until WIFI is available
[E][WiFiUdp.cpp:219] parsePacket(): could not receive data: 5
Waiting to connect to MQTT until WIFI is available
[E][WiFiUdp.cpp:219] parsePacket(): could not receive data: 5
Waiting to connect to MQTT until WIFI is available
[E][WiFiUdp.cpp:219] parsePacket(): could not receive data: 5
Not updating NTP because WIFI is not available
Waiting to connect to MQTT until WIFI is available
[E][WiFiUdp.cpp:219] parsePacket(): could not receive data: 5
Waiting to connect to MQTT until WIFI is available
[E][WiFiUdp.cpp:219] parsePacket(): could not receive data: 5
Waiting to connect to MQTT until WIFI is available
[E][WiFiUdp.cpp:219] parsePacket(): could not receive data: 5
Waiting to connect to MQTT until WIFI is available
[E][WiFiUdp.cpp:219] parsePacket(): could not receive data: 5
Waiting to connect to MQTT until WIFI is available
[E][WiFiUdp.cpp:219] parsePacket(): could not receive data: 5
Waiting to connect to MQTT until WIFI is available
[E][WiFiUdp.cpp:219] parsePacket(): could not receive data: 5
Waiting to connect to MQTT until WIFI is available
[E][WiFiUdp.cpp:219] parsePacket(): could not receive data: 5
Waiting to connect to MQTT until WIFI is available
[E][WiFiUdp.cpp:219] parsePacket(): could not receive data: 5
Waiting to connect to MQTT until WIFI is available
[E][WiFiUdp.cpp:219] parsePacket(): could not receive data: 5
```

lptr, 2022-01-19:
An explanation could be the following: there is a power outage, and the router and the ESP boot up at the same time, and the router takes longer than the 20 seconds timeout for the ESP, and thus the ESP just stops trying to connect.

This shouldn't be the case, as we should be retrying the connection if it's unavailable, but maybe something's wrong with that code.

A way to confirm would be to restart everything and observe the same phenomena, then restart only the ESP with the router already up to see it working.

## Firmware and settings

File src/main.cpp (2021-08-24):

#ifdef ESP32
#include "pins_arduino_ttgo_call.h"
#endif

#include <Arduino.h>
#include <ArduinoJson.h>

#include "Door.h"
#include "FileSystemHandler.h"
#include "HttpUpdateHandler.h"
#include "LightHandler.h"
#include "MqttHandler.h"
#include "NtpHandler.h"
#include "OtaHandler.h"
#include "SwitchHandler.h"
#include "Telemetry.h"
#include "WiFiHandler.h"
#include "version.h"

FileSystemHandler fileSystem;
Config config(fileSystem);
OtaHandler ota;
WiFiHandler wifi(config, "chickens");

LightHandler light(config);
SwitchHandler openSwitch("openSwitch", OPEN_PIN, []() { return config.invertOpenSwitch; });
SwitchHandler closeSwitch("closedSwitch", CLOSED_PIN, []() { return config.invertCloseSwitch; });
Door door(config, openSwitch, closeSwitch);

NtpHandler ntp(wifi);
MqttHandler mqtt(wifi, ntp);
HttpUpdateHandler httpUpdateHandler(wifi);
CompositeTelemetryProvider telemetryProvider({ &light, &openSwitch, &closeSwitch, &door });
TelemetryPublisher telemetryPublisher(config, mqtt, "events", telemetryProvider);

void fatalError(String message) {
    Serial.println(message);
    delay(10000);
    ESP.restart();
}

void setup() {
    Serial.begin(115200);

    pinMode(RESET_BUTTON_PIN, INPUT_PULLUP);

#if defined(SIM800_POWER)
    // Disable SIM800 module on LilyGo board
    pinMode(SIM800_POWER, OUTPUT);
    digitalWrite(SIM800_POWER, LOW);
#endif

    while (!Serial) {
        delay(100);
    }

    Serial.println("Starting up file system...");
    if (!fileSystem.begin()) {
        fatalError("Could not initialize file system");
        return;
    }

    bool reset = digitalRead(RESET_BUTTON_PIN) == LOW;
    config.begin(reset);

    wifi.begin();
    ota.begin("chickens");

    File mqttConfigFile = fileSystem.getFS().open("/mqtt-config.json", FILE_READ);
    DynamicJsonDocument mqttConfigJson(mqttConfigFile.size() * 2);
    DeserializationError error = deserializeJson(mqttConfigJson, mqttConfigFile);
    if (error) {
        fatalError("Failed to read MQTT config file at /mqtt-config.json: " + String(error.c_str()));
        return;
    }
    mqtt.begin(
        mqttConfigJson,
        [](const JsonDocument& json) {
            config.update(json);
            config.store();
            Serial.println("Updated local configuration");
        },
        [](const JsonDocument& json) {
            if (json.containsKey("restart")) {
                Serial.println("Restart command received, restarting");
                ESP.restart();
            } else if (json.containsKey("moveTo")) {
                long targetPosition = json["moveTo"];
                Serial.println("Moving door to " + String(targetPosition));
                door.moveTo(targetPosition);
            } else if (json.containsKey("override")) {
                int targetStateValue = json["override"];
                GateState targetState = static_cast<GateState>(targetStateValue);
                Serial.println("Setting door state to " + String(targetStateValue));
                door.override(targetState);
            } else if (json.containsKey("resume")) {
                Serial.println("Resuminmg normal operation");
                door.resume();
            } else if (json.containsKey("update")) {
                String url = json["update"];
                httpUpdateHandler.update(url, VERSION);
            } else {
                Serial.println("Unknown command");
            }
        });

    light.begin(LIGHT_SDA, LIGHT_SCL);
    openSwitch.begin();
    closeSwitch.begin();
    door.begin([](std::function<void(JsonObject&)> populateEvent) {
        DynamicJsonDocument doc(2048);
        JsonObject root = doc.to<JsonObject>();
        root["version"] = VERSION;
        JsonObject event = root.createNestedObject("event");
        populateEvent(event);
        JsonObject telemetry = root.createNestedObject("telemetry");
        telemetryProvider.populateTelemetry(telemetry);
        return mqtt.publish("status", doc);
    });
    light.setOnUpdate([](float light) {
        door.lightChanged(light);
    });
    telemetryPublisher.begin();
}

void loop() {
    ota.loop();
    light.loop();
    bool moving = door.loop();
    if (wifi.loop()) {
        telemetryPublisher.loop();
        ntp.loop();
        mqtt.loop();
    }
    if (!moving) {
        delay(100);
    }
}

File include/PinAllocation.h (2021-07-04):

#pragma once

#if defined(ESP32)

#include "pins_arduino_ttgo_call.h"

#define MOTOR_PIN1 GPIO_NUM_23
#define MOTOR_PIN2 GPIO_NUM_19
#define MOTOR_PIN3 GPIO_NUM_18
#define MOTOR_PIN4 GPIO_NUM_5

#if defined(MK1)
// The original with 5V stepper motor
#define LIGHT_SDA GPIO_NUM_15
#define LIGHT_SCL GPIO_NUM_13
#elif defined(MK3)
// Updated with 12V stepper and light sensor on default I2C PINs
#define LIGHT_SDA GPIO_NUM_21
#define LIGHT_SCL GPIO_NUM_22
#else
#error "Please define MK1 or MK3 for ESP32"
#endif

#define OPEN_PIN GPIO_NUM_14
#define CLOSED_PIN GPIO_NUM_12

#define RESET_BUTTON_PIN GPIO_NUM_2

#elif defined(ESP8266)

#define OPEN_PIN D5
#define CLOSED_PIN D6

#define MOTOR_PIN1 D0
#define MOTOR_PIN2 D3
#define MOTOR_PIN3 D4
#define MOTOR_PIN4 D8

#define LIGHT_SCL D1
#define LIGHT_SDA D2

#define RESET_BUTTON_PIN D7

#endif

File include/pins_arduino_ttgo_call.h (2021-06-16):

#ifndef Pins_Arduino_h
#define Pins_Arduino_h

#include <stdint.h>

#define EXTERNAL_NUM_INTERRUPTS 16
#define NUM_DIGITAL_PINS        20
#define NUM_ANALOG_INPUTS       16

#define analogInputToDigitalPin(p)  (((p)<20)?(esp32_adc2gpio[(p)]):-1)
#define digitalPinToInterrupt(p)    (((p)<40)?(p):-1)
#define digitalPinHasPWM(p)         (p < 34)

// Sim800
#if defined(SIM800C)
#define SIM800_TX 27
#define SIM800_RX 26
#define PWKEY 4
#define SIM800_RST -1
#define SIM800_POWER 25

static const uint8_t LED_BUILTIN = 12;
#elif defined(SIM800L)
#define SIM800_TX 26
#define SIM800_RX 27
#define PWKEY 4
#define SIM800_RST 5
#define SIM800_POWER 23

static const uint8_t LED_BUILTIN = 13;
#endif

#define BUILTIN_LED  LED_BUILTIN // backward compatibility

static const uint8_t TX = 1;
static const uint8_t RX = 3;

static const uint8_t SDA = 21;
static const uint8_t SCL = 22;

static const uint8_t SS    = 18;
static const uint8_t MOSI  = 27;
static const uint8_t MISO  = 19;
static const uint8_t SCK   = 5;

static const uint8_t A0 = 36;
static const uint8_t A3 = 39;
static const uint8_t A4 = 32;
static const uint8_t A5 = 33;
static const uint8_t A6 = 34;
static const uint8_t A7 = 35;

static const uint8_t A10 = 4;
static const uint8_t A11 = 0;
static const uint8_t A12 = 2;
static const uint8_t A14 = 13;
static const uint8_t A16 = 14;
static const uint8_t A18 = 25;

static const uint8_t T0 = 4;
static const uint8_t T1 = 0;
static const uint8_t T2 = 2;
static const uint8_t T4 = 13;
static const uint8_t T6 = 14;
static const uint8_t T8 = 33;
static const uint8_t T9 = 32;

static const uint8_t DAC1 = 25;

#endif /* Pins_Arduino_h */

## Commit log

2020-11-14 Add 3D models
    [ESP8266 v7.f3d, ESP8266 v7.stp, Led RGB v4.f3d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]
2020-11-14 Use AccelStepper to rotate motor
2020-11-15 Switch off motor when not in use
2020-11-18 Add Hall sensor module info
2020-11-18 Add switch state
2020-11-18 Polish OTA error reporting
    [main.cpp]
2020-11-21 Use D7 and D4 for light sensor
2020-11-21 Reverse direction of open/close
    [main.cpp]
2020-11-24 Invert motor direction
2020-11-24 Use a PULLUP input for reed relays
2020-11-24 Fix typo in motorPosition
    [main.cpp]
2020-11-24 Use web socket-only communication with server
2020-11-24 Allow updating gate state and motor position from web UI
2021-02-26 Add support for ESP32 (LilyGo TTGO Call)
2021-03-26 No need to define ESP32
    It is already defined by the platform.
2021-03-26 Add Google Cloud connectors
2021-03-26 Add bit more debug to WiFi connection
    Sometimes it just doesn't want to connect, but will work fine after a couple resets. :o
    [main.cpp]
2021-03-29 Fix millis() rollover bugs
    Since millis() returns a 32-bit long, there will be an overflow every ~50 days that was left unhandled. This way it should work.
    https://www.norwegiancreations.com/2018/10/arduino-tutorial-avoiding-the-overflow-issue-when-using-millis-and-micros/
2021-03-30 Do not subscribe to errors
    What is this even?
    [mqtt-handler.cpp]
2021-03-31 Only check on MQTT every 5 seconds
    This prevents the loop from slowing the motor down
    [mqtt-handler.cpp]
2021-03-31 Move pin allocations to separate header file
2021-04-01 Do not run motor when it's disabled
2021-04-01 Emergency stop after timeout
    To prevent door from jamming, overheating or breaking itself.
    [Door.cpp]
2021-04-05 Move switch handling to its own class
2021-04-05 Handle fatal errors in a fatal way
    [main.cpp]
2021-04-08 Move handling switch telemetry out
2021-04-13 Remove GPRS option
    We will have a separate device to handle communication.
2021-04-13 Transmit MQTT while moving, too
    We can do this, since we are now using hardware SSL as part of the WiFi, and so it's not going to slow down the movement too much.
    [main.cpp]
2021-04-13 Move pin allocation headers around a bit
2021-04-13 Fix build for ESP8266
    - Move FileSystemHandler to its own class
    - Use ESP8266 WIFI library
    - Do not rely on exception handling
    [Config.cpp, PinAllocation.h, WiFiHandler.cpp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]
2021-04-15 Fix loading config
    We accidentally loaded the open light limit even for the close light limit.
    [Config.cpp]
2021-04-16 Close door on init if none of the switches are engaged
2021-04-25 Add reset button to ignore stored configuration
    If the button is pressed during startup, the configuration stored on the file system is ignored.
2021-05-22 Manual override to reset movement timeout
    Previously manual override did not reset the movement timeout, and could result in a timeout when the state was overridden right after the door opened or closed.
    [main.cpp]
2021-05-22 Halt if both switches are engaged
2021-05-22 Fix HTTP update for ESP8266
    [main.cpp]
2021-05-22 Link to description of Google IoT device private key config
2021-05-22 Re-allocate pins for ESP8266
    We need to have the pullup stuff on pins that can handle them, and moved the SDA/SCL for the light sensor to the official SDA/SCL pins.
2021-06-04 Keep track of latest heartbeat in Firebase
2021-06-04 Add check-heartbeat function
    This checks the heartbeat of every device that publishes its heartbeat in the "heartbeats" collection.
2021-06-13 Move door slower
    This helps with moving the door when it is slightly jammed. We are not rushing anywhere either.
    [Door.cpp]
2021-06-14 Use mqttConnectAsync() to connect
    This does not avoid the sync connection, actually, but it does not loop if the first attempt does not succeed.
    [MqttHandler.cpp]
2021-06-14 Inlcude device ID in Slack messages
2021-06-16 Disable SIM on LilyGo board
    It is possible that it draws current at some points in time, causing the system to malfunction.
2021-06-18 Polish reading switch
2021-06-18 Do not initialize output PIN
    We are using that pin for reading the close switch right now.
2021-07-03 Add MK3 variant with 12V motor and regular I2C pins for light sensor
2021-08-08 Use interrupts to get switch states
2021-08-20 Do not use interrupts to read door switches
2021-08-22 Only employ MDNS workarund on ESP32
2021-08-23 Upgrade ArduinoJson
2021-08-23 Upgrade light sensor library
